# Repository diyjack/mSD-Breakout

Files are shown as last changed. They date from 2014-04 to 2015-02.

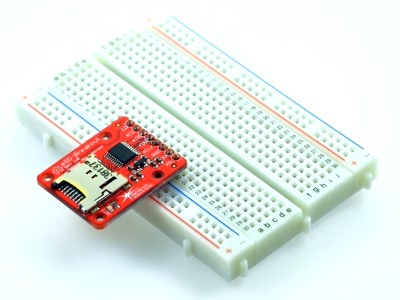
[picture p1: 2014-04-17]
pcb/mSD-Breakout_v10.jpg

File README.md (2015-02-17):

# mSD-Breakout
Breakout with microSD socket and level shifter.

mSD-Breakout (http://www.watterott.com/en/mSD-Breakout)

## Shop
* [mSD-Breakout](http://www.watterott.com/en/mSD-Breakout)

## Features
* microSD socket (SPI) support SD and SDHC cards (up to 32GB)
* 5V tolerant inputs (level shifter)
* on-board 3.3V voltage regulator

## Hardware and Software
* [Schematics + Layout](https://github.com/watterott/mSD-Breakout/tree/master/pcb)

* Arduino Uno Connection (Example Sketch: ```File->Examples->SD->CardInfo```):
    ```
    Uno -> Breakout
    ---------------
    5V  -> 5V
    GND -> GND
    D13 -> CLK
    D12 -> DO (MISO)
    D11 -> DI (MOSI)
    D4  -> CS
    ```

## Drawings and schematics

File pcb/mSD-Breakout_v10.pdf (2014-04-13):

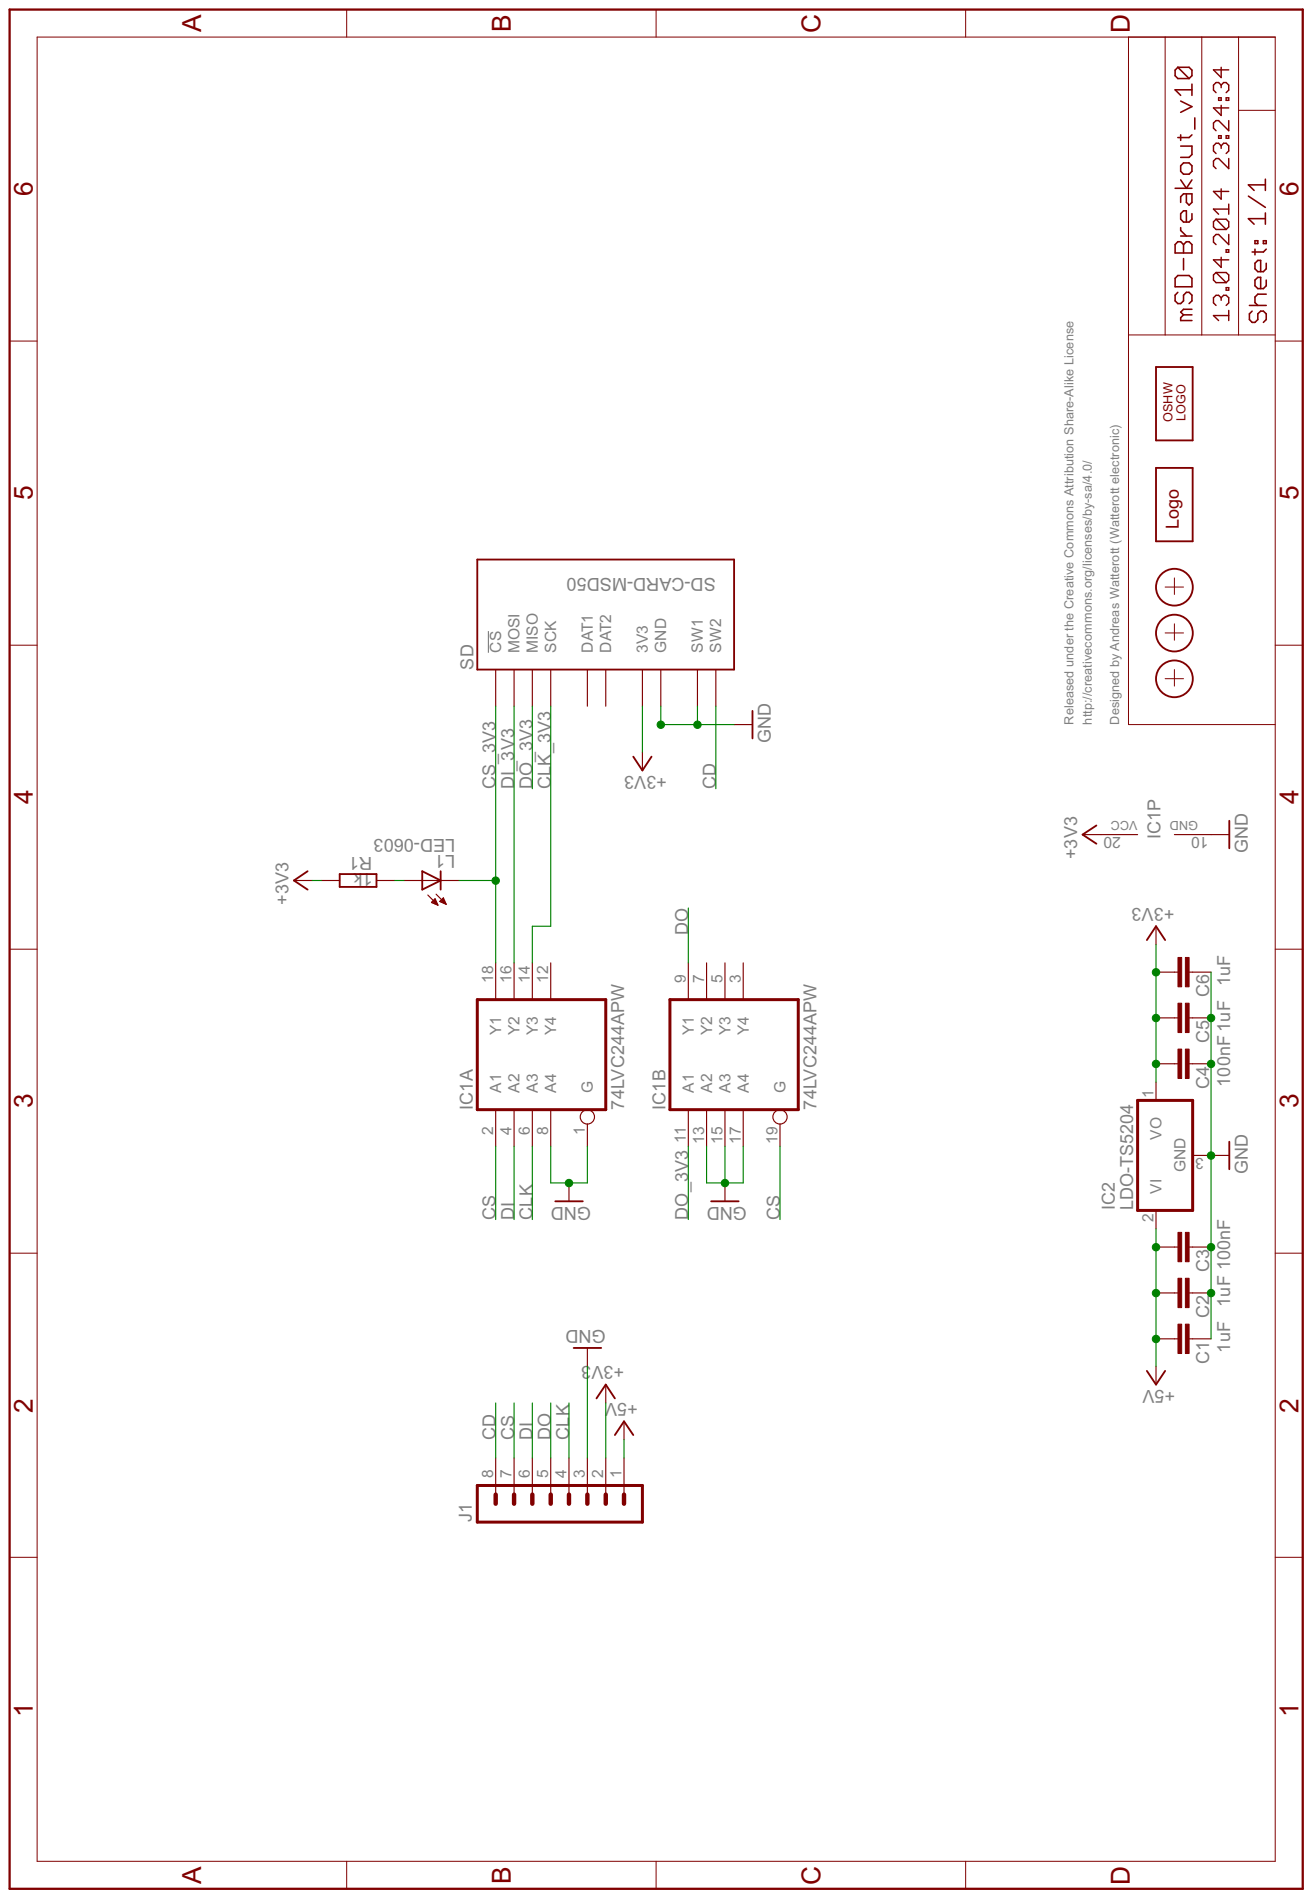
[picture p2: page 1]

GND 100nF 100nF 1uF 3V3+ 1uF V5+ LDO-TS520 74 4LVC244APW 74LVC244APW DNG3V3+V5+ GND +3V3 GND 3V3+ DNG k1 1uF 1uF 3060- DEL +3V3 DNG Released under the Creative Commons Attribution Share-Alike License http://creativecommons.org/licenses/by-sa/4.0/ Designed by Andreas Watterott (Watterott electronic) C3 C4 C2 C5 DAT2 CSMOSI 3V3 SCK GND MISO DAT1 SW1 SW2 SD 05DS M- DRAC- DS IC2 GND VI 2 3 VO 1 IC1AG 1 A1 2 A2 4 A3 6 A4 8 Y4 12 Y3 14 Y2 16 Y1 18 IC1BG 19 A1 11 A2 13 A3 15 A4 17 Y4 3 Y3 5 Y2 7 Y1 9 IC1PCCV DNG 02 01 J1 87654321 1R C6 C1 1L CD CD DO DO DI DI CLK CLK CS CSCS DI_3V3 CS_3V3 CLK_3V3 DO_3V3 DO_3V3 ABCD 1 2 3 4 5 6 ABCD 1 2 3 4 5 6 OSHW LOGO Logo

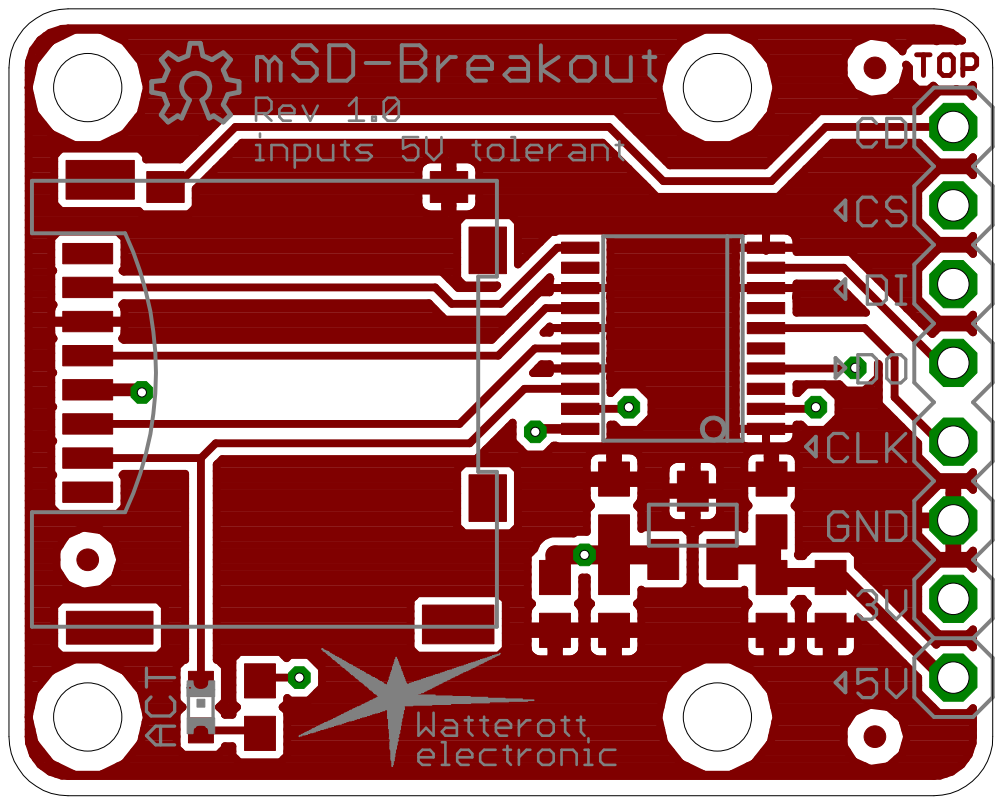
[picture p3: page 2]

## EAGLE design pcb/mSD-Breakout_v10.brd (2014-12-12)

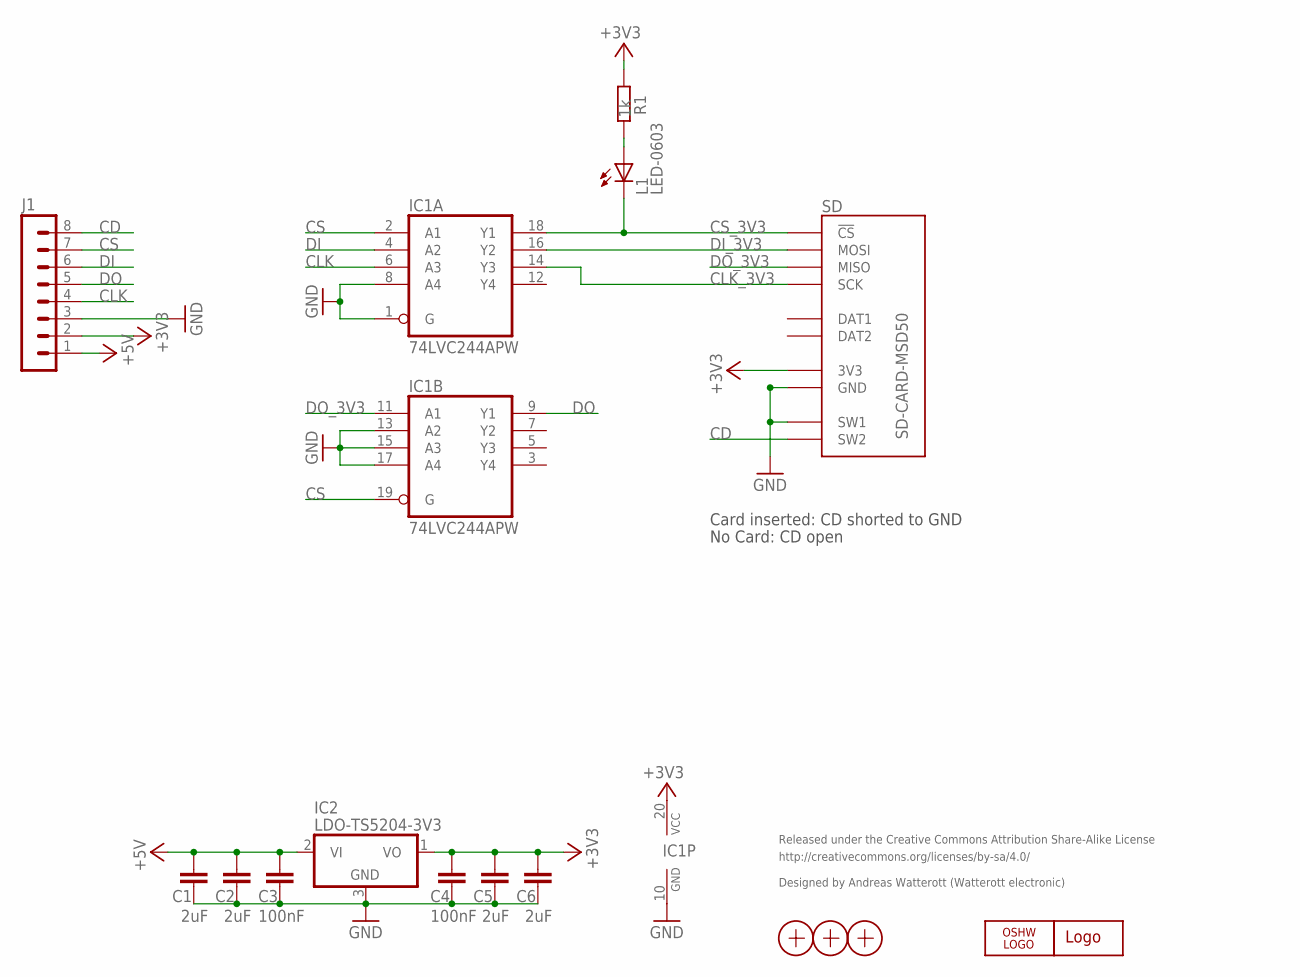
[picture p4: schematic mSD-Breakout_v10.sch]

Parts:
C1, C2, C5, C6: 2uF; C0603
C3, C4: 100nF; C0603
IC1: 74LVC244APW; TSSOP20
IC2: LDO-TS5204-3V3; SOT23
J1: MA08-1
L1: LED-0603; LED_0603
LOGO1: OSHW_LOGOX0100; OSHW_6X100
LOGO2: LOGO-SPARK_PLACE; SPARK_TPLACE
R1: 1k; R0603
SD: SD-CARD-MSD50; SD_5031821853
X1, X2, X3: PASSER

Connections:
+3V3: C4.1, C5.1, C6.1, IC1.20 (VCC), IC2.1 (VO), J1.2, R1.1, SD.VCC (3V3)
+5V: C1.1, C2.1, C3.1, IC2.2 (VI), J1.1
CD: J1.8, SD.SW2
CLK: IC1.6 (A3), J1.4
CLK_3V3: IC1.14 (Y3), SD.SCK
CS: IC1.2 (A1), IC1.19 (G), J1.7
CS_3V3: IC1.18 (Y1), L1.C, SD.CS (!CS)
DI: IC1.4 (A2), J1.6
DI_3V3: IC1.16 (Y2), SD.MOSI
DO: IC1.9 (Y1), J1.5
DO_3V3: IC1.11 (A1), SD.MISO
GND: C1.2, C2.2, C3.2, C4.2, C5.2, C6.2, IC1.1 (G), IC1.8 (A4), IC1.10 (GND), IC1.13 (A2), IC1.15 (A3), IC1.17 (A4), IC2.3 (GND), J1.3, SD.GND, SD.SW1
unnamed: L1.A, R1.2

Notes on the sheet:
Released under the Creative Commons Attribution Share-Alike License
http://creativecommons.org/licenses/by-sa/4.0/
Designed by Andreas Watterott (Watterott electronic)
Card inserted: CD shorted to GND
No Card: CD open

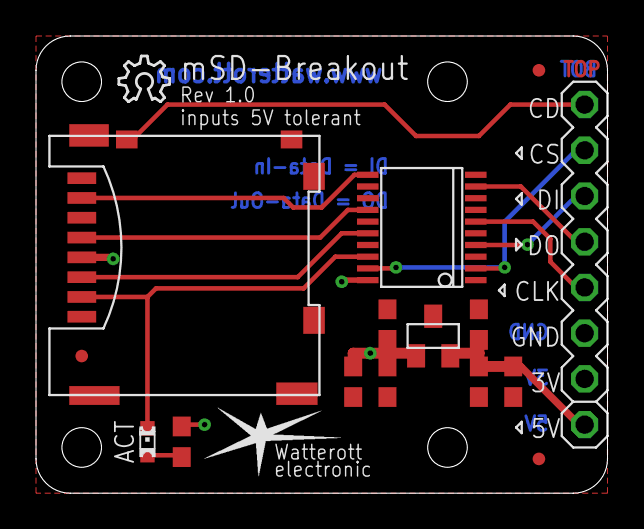
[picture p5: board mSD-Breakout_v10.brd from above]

Board: 2 copper layers, 31.8 x 25.4 mm, 17 parts (0 on the bottom side), 13 nets.

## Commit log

2014-04-13 added schematic and layout files
    [mSD-Breakout_v10.brd, mSD-Breakout_v10.sch]
2014-05-24 updated schematics
    [mSD-Breakout_v10.brd, mSD-Breakout_v10.sch]
2014-08-15 updated schematic and layout files
    [mSD-Breakout_v10.brd, mSD-Breakout_v10.sch]
2014-08-21 updated layout and schematics
    [mSD-Breakout_v10.brd]
2014-11-06 cleaned up schematics and layout
    [mSD-Breakout_v10.brd, mSD-Breakout_v10.sch]
